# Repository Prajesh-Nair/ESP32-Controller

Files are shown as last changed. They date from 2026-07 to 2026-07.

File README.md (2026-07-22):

# J-Deck

<p align="center">
  <strong>An ESP32-C3 wireless controller for JATAYU and any Wi-Fi, Bluetooth, or ESP-NOW project.</strong><br />
  Compact in your hands. Fast on the link. Built to control.
</p>

<p align="center">
  
  
  
  
</p>

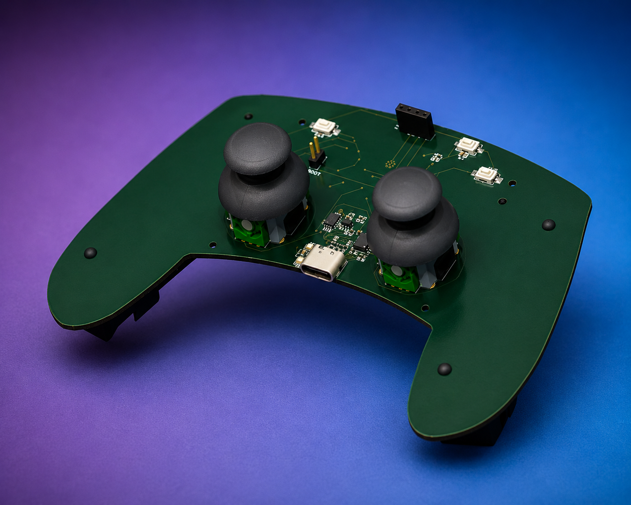
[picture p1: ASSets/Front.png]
J-Deck hero image - assembled remote


## Built for JATAYU. Ready for anything.

J-Deck is a purpose-built handheld wireless controller. Its primary role is to talk directly to the **JATAYU Flight Controller**, reading pilot inputs from twin analog joysticks and tactile controls before sending compact control data over **ESP-NOW**.

But it is not limited to flight. With its ESP32-C3 radio and programmable firmware, J-Deck can be adapted as a controller for robots, RC vehicles, smart-home projects, camera rigs, simulators, or any device that communicates through **Wi-Fi**, **Bluetooth Low Energy (BLE)**, or **ESP-NOW**.

No router is required for ESP-NOW. For other projects, choose the wireless mode and control protocol that best fits the device you are building.

> This repository contains the KiCad hardware design for the controller. Firmware, final protocol definitions, pin mappings, and flight-safety behaviour should be kept versioned alongside the matching JATAYU Flight Controller project.

## Wireless modes

| Mode | Great for | Typical connection |
| --- | --- | --- |
| ESP-NOW | Responsive device-to-device control, including JATAYU | Direct peer-to-peer packets; no access point required |
| Wi-Fi | Web dashboards, LAN-connected devices, and IoT projects | Connect through an access point or run a local access point |
| Bluetooth LE | Phones, tablets, and low-power nearby peripherals | BLE pairing and GATT services |

The controller hardware stays the same; the firmware defines the selected radio mode, packet format, mapping, and receiver behaviour.

## The link

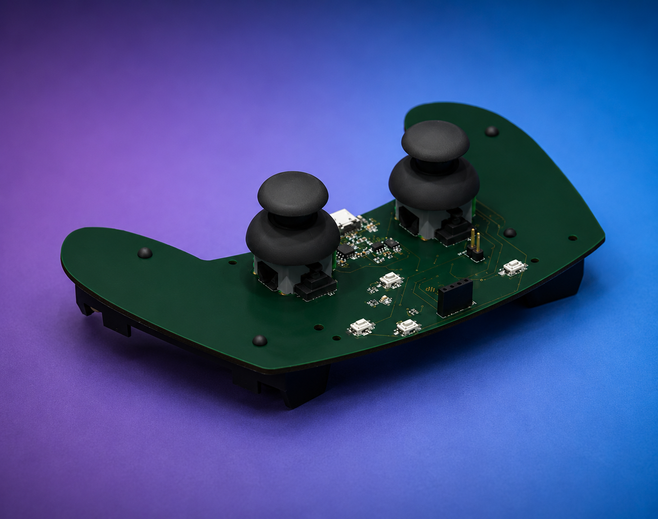
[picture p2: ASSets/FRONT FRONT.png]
ESP-NOW telemetry flow placeholder - replace with a protocol or range-test graphic


```text
[J-Deck] -- ESP-NOW control packets --> [JATAYU Flight Controller]
[J-Deck] <-- optional telemetry ----- [JATAYU Flight Controller]
```

ESP-NOW is a strong fit for a dedicated RC link because it operates without a conventional Wi-Fi access point and keeps the radio exchange focused on the aircraft. The exact packet format, peer MAC addresses, update rate, channel, checksum, and failsafe timeout are firmware decisions - document them here when the flight stack is locked.

## Hardware

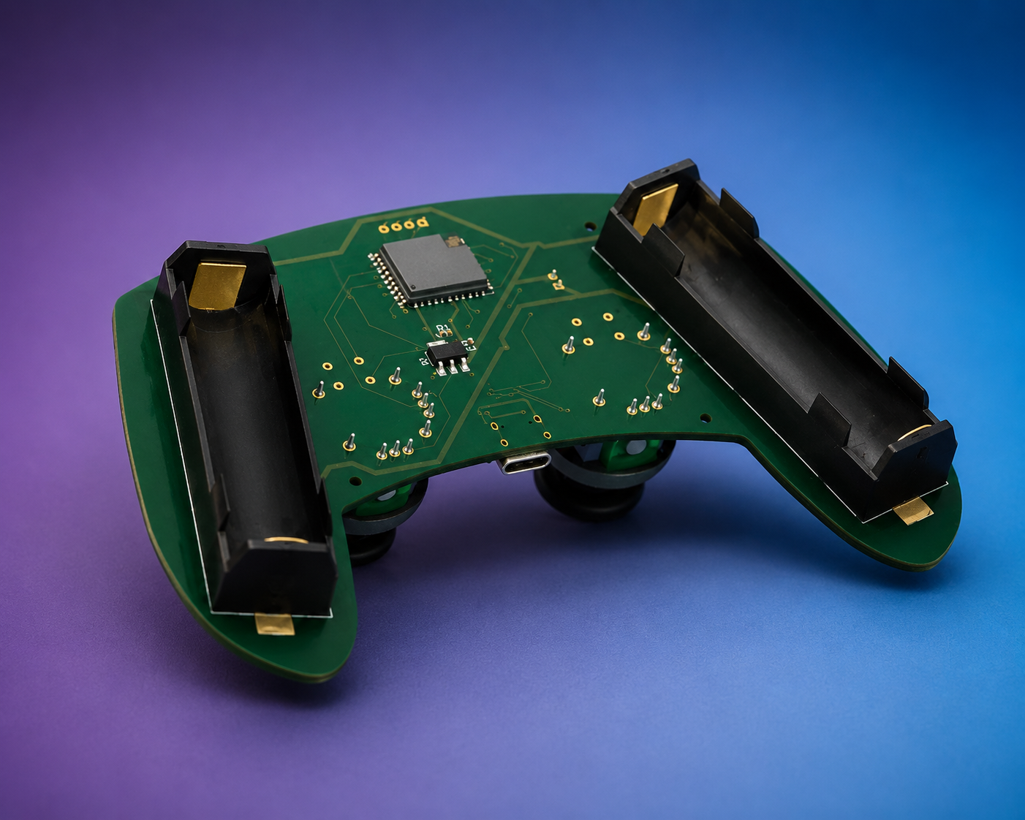
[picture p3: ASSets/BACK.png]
PCB render placeholder - replace with front/back board render or assembled-controller photo


| Feature | Design choice |
| --- | --- |
| Brain | ESP32-C3-WROOM-02U - RISC-V MCU with 2.4 GHz radio |
| Flight controls | Two 2-axis analog joysticks |
| Extra input | Four tactile push buttons |
| Charging | USB-C input with TP4056 single-cell LiPo charger |
| Battery protection | DW01A + FS8205A protection stage |
| Regulation | AP2114H 3.3 V LDO |
| Feedback | Charge/status LEDs |

## Power

The controller is designed around a **single-cell 3.7 V LiPo battery**. USB-C feeds the onboard charger, while the battery protection circuit guards against over-charge, over-discharge, and over-current conditions. The 3.3 V regulator supplies the ESP32-C3 and controls.

**Treat lithium batteries with care:** use a protected, suitable 1S cell; inspect wiring and polarity before power-up; and never leave charging unattended.

## Repository map

```text
JATAYU-Controller.kicad_pro   KiCad project
JATAYU-Controller.kicad_sch   Schematic
JATAYU-Controller.kicad_pcb   PCB layout
JATAYU-Controller-BOM.csv     Bill of materials
GERBER/                       Manufacturing outputs
3D Files/                     Mechanical / enclosure assets
```

## Getting started

1. Open `JATAYU-Controller.kicad_pro` in KiCad.
2. Review the schematic, footprints, board rules, and antenna keep-out before ordering.
3. Generate fresh manufacturing files from the validated board revision.
4. Assemble and bring up the power rails first, then program and test the ESP-NOW firmware with the JATAYU Flight Controller.
5. Validate radio range, packet loss, neutral-stick calibration, arming logic, and failsafe behaviour **with props removed** before any flight test.

## Flight safety

This is an experimental flight-control device. A radio link must never be the only safety layer. The aircraft firmware should implement a conservative failsafe when packets stop arriving, reject malformed packets, require deliberate arming, and be tested in a controlled environment. Always follow applicable local regulations.

## Image checklist

The three placeholder images above are ready to be replaced with your own project shots:

1. A clean, assembled-controller hero photo.
2. An ESP-NOW architecture, telemetry, or range-test graphic.
3. A KiCad 3D render or close-up PCB photo.

---

<p align="center">Made for the <strong>JATAYU</strong> flight platform.</p>

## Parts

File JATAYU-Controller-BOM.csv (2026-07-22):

Reference | Qty | Value | DNP | Exclude from BOM | Exclude from Board | Footprint | Datasheet
Battery1 | 1 | Conn_01x02_Pin |  |  |  | Connector_PinHeader_2.54mm:PinHeader_1x02_P2.54mm_Vertical | ~
C1,C2,C4,C5 | 4 | 10uF |  |  |  | Capacitor_SMD:C_0603_1608Metric | https://robu.in/product/0603x106m160nt-fh-16v-10uf-x5r%c2%b120-0603-multilayer-ceramic-capacitors-mlcc-smd-smt-rohs/,~
C3 | 1 | 0.1uF |  |  |  | Capacitor_SMD:C_0603_1608Metric | ~
C7 | 1 | 1uF |  |  |  | Capacitor_SMD:C_0603_1608Metric | https://robu.in/product/0603b105k160nt-fh-16v-1uf-x7r%c2%b110-0603-multilayer-ceramic-capacitors-mlcc-smd-smt-rohs/
D1,D2 | 2 | CHRG-LED |  |  |  | LED_SMD:LED_0805_2012Metric | ~
D5 | 1 | LED |  |  |  | LED_SMD:LED_0805_2012Metric | ~
J1 | 1 | USB_C_Receptacle_USB2.0_14P |  |  |  | Connector_USB:USB_C_Receptacle_GCT_USB4105-xx-A_16P_TopMnt_Horizontal | https://robu.in/product/type-c-31-m-12-hroparts-5a-1-16p-female-type-c-smd-usb-connectors-rohs/?gad_source=1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
J2 | 1 | Conn_01x04_Socket |  |  |  | Connector_PinSocket_2.54mm:PinSocket_1x04_P2.54mm_Vertical | ~
Q1 | 1 | FS8205A |  |  |  | FS8205A:SOP65P640X120-8N
R1,R2 | 2 | 22 |  |  |  | Resistor_SMD:R_0603_1608Metric | https://robu.in/product/ac0603fr-0722rl-yageo-res-thick-film-0603-22-ohm-1-0-1w1-10w-%c2%b1100ppm-c-pad-smd-t-r-automotive-aec-q200/
R3,R8 | 2 | 5.1K |  |  |  | Resistor_SMD:R_0603_1608Metric | https://robu.in/product/rt0603fre075k1l-yageo-100mw-thin-film-resistor-75v-%c2%b150ppm-%e2%84%83-%c2%b11-5-1k%cf%89-0603-chip-resistor-surface-mount-rohs/
R4 | 1 | 1.2K |  |  |  | Resistor_SMD:R_0603_1608Metric | ~
R5 | 1 | 0.4 |  |  |  | Resistor_SMD:R_0603_1608Metric | ~
R6,R7,R9 | 3 | 1K |  |  |  | Resistor_SMD:R_0603_1608Metric | ~
R10 | 1 | 100 |  |  |  | Resistor_SMD:R_0603_1608Metric | ~
R14,R15 | 2 | 10K |  |  |  | Resistor_SMD:R_0603_1608Metric | https://robu.in/product/ac0603fr-0710kl-yageo-res-thick-film-0603-10k-ohm-1-0-1w1-10w-%c2%b1100ppm-c-pad-smd-t-r-automotive-aec-q200/
R16 | 1 | 220 |  |  |  | Resistor_SMD:R_0603_1608Metric | ~
SW1,SW2,SW3,SW4 | 4 | SW_Push |  |  |  | Button_Switch_SMD:SW_Tactile_SPST_NO_Straight_CK_PTS636Sx25SMTRLFS | https://robu.in/product/tsb008a2526a-bzcn-3-5mm-2-5mm-rectangle-button-50ma-standing-paste-6mm-260gf-12v-smd-tactile-switches-rohs/,~
U1 | 1 | Stick 1 |  |  |  | COM-09032:XDCR_COM-09032
U2 | 1 | Stick 2 |  |  |  | COM-09032:XDCR_COM-09032
U3 | 1 | TP4056 |  |  |  | Package_SO:SOIC-8-1EP_3.9x4.9mm_P1.27mm_EP2.41x3.3mm_ThermalVias | https://www.lcsc.com/datasheet/lcsc_datasheet_2410121619_TOPPOWER-Nanjing-Extension-Microelectronics-TP4056-42-ESOP8_C16581.pdf
U4 | 1 | DW01A |  |  |  | Package_TO_SOT_SMD:SOT-23-6 | https://hmsemi.com/downfile/DW01A.PDF
U5 | 1 | AP2114H-3.3TRG1 |  |  |  | Package_TO_SOT_SMD:SOT-223-3_TabPin2 | https://www.lioncircuits.com/parts/AP2114H-3.3TRG1
U6 | 1 | ESP32-C3-WROOM-02U |  |  |  | RF_Module:ESP32-C3-WROOM-02U | https://www.espressif.com/sites/default/files/documentation/esp32-c3-wroom-02_datasheet_en.pdf

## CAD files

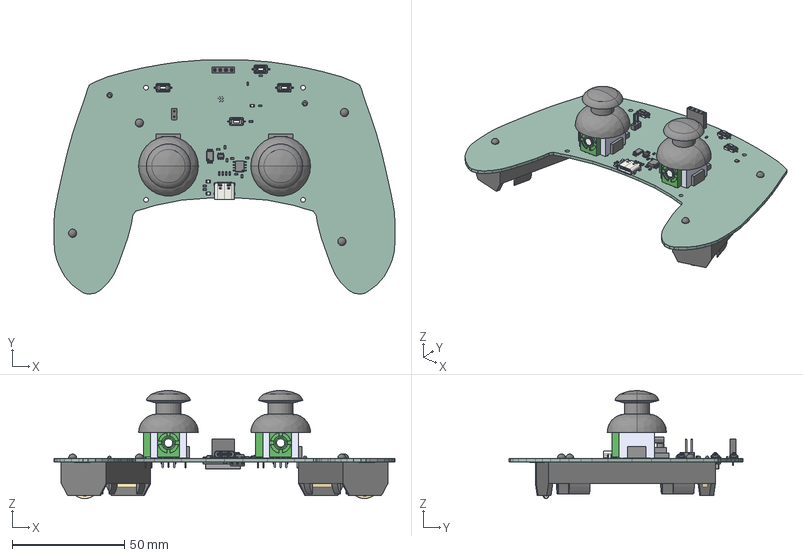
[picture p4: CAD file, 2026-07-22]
3D Files/JATAYU-Controller-PCB.step
152.0 x 104.5 x 48.2 mm
SW_Tactile_SPST_NO_Straight_CK_PTS636Sx25SMTRLFS x 4
COM-09032 x 2
C_0603_1608Metric x 6
R_0603_1608Metric x 13
SOT-23-6
LED_0805_2012Metric x 3
FS8205A
TP4056--3DModel-STEP-56544
PinHeader_1x02_P2.54mm_Vertical
PinSocket_1x04_P2.54mm_Vertical
USB_C_Receptacle_GCT_USB4105-xx-A_16P_TopMnt_Horizontal
SOT-223
BatteryHolder_Keystone_1042_1x18650 x 2
ESP32-C3-WROOM-02U
JATAYU-Controller_PCB

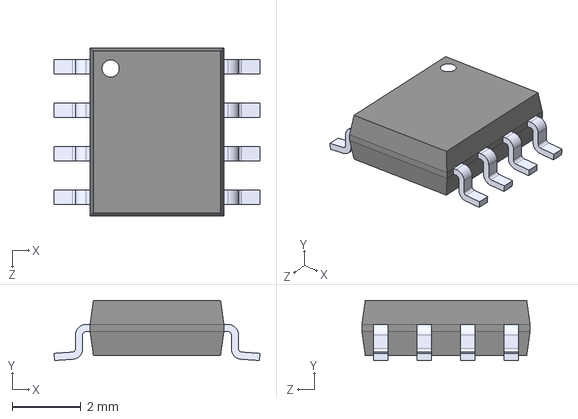
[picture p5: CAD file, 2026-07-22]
EXTRA ASSETS FOR KICAD/COM-09032/TP4056--3DModel-STEP-56544.STEP
6.00 x 1.75 x 4.90 mm

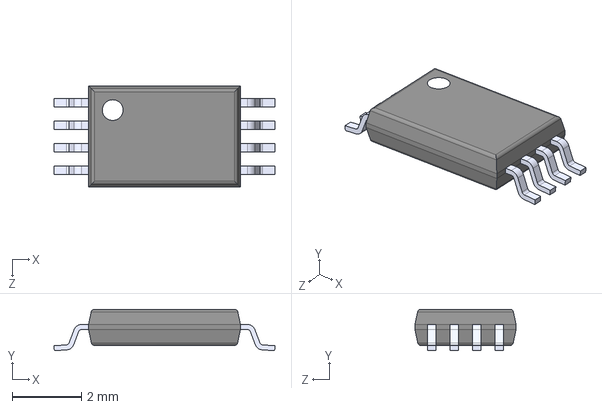
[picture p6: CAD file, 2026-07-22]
EXTRA ASSETS FOR KICAD/FS8205A/FS8205A.step
6.40 x 1.20 x 2.93 mm

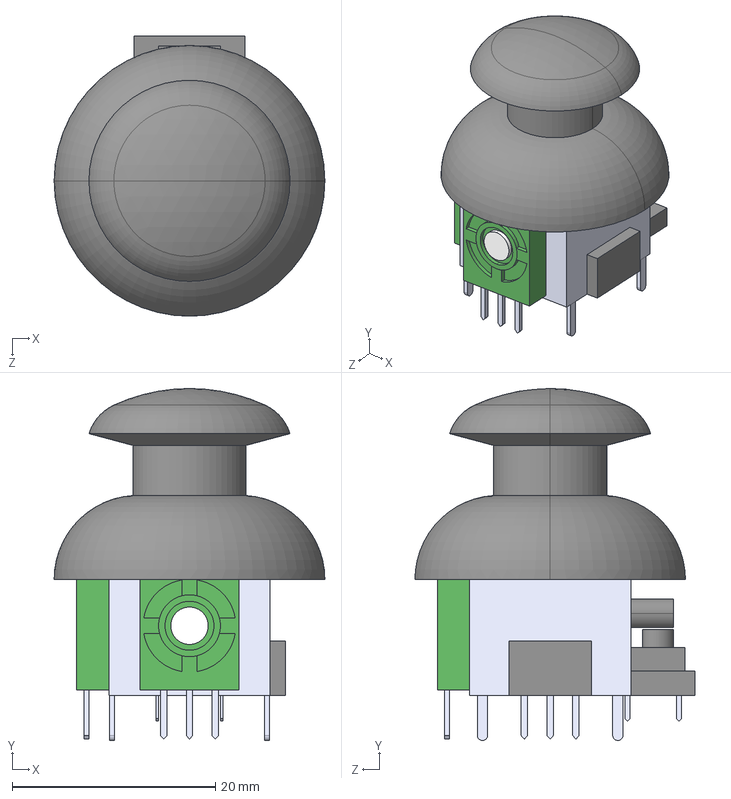
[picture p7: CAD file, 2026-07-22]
EXTRA ASSETS FOR KICAD/COM-09032/COM-09032.step
26.7 x 34.7 x 27.6 mm

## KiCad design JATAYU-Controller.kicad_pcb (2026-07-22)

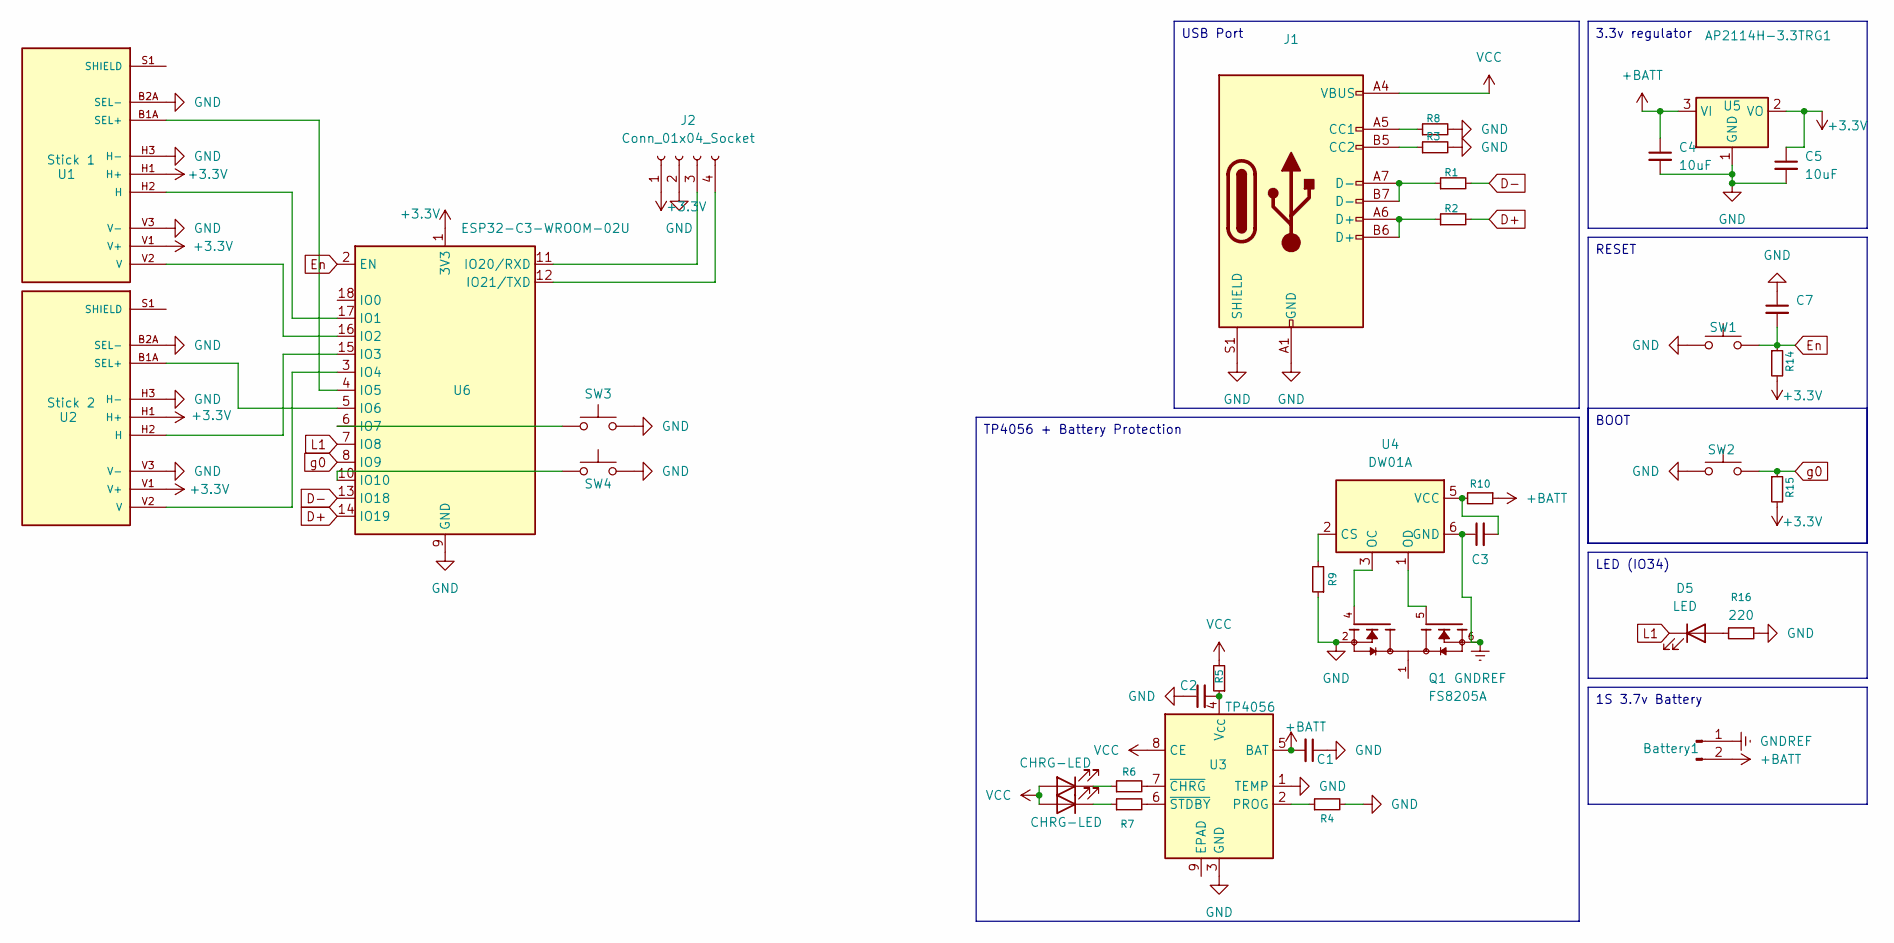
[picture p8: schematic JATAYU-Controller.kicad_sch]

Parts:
Battery1: Conn_01x02_Pin; PinHeader_1x02_P2.54mm_Vertical
C1, C2, C4, C5: 10uF; C_0603_1608Metric
C3: 0.1uF; C_0603_1608Metric
C7: 1uF; C_0603_1608Metric
D1, D2: CHRG-LED; LED_0805_2012Metric
D5: LED; LED_0805_2012Metric
J1: USB_C_Receptacle_USB2.0_14P; USB_C_Receptacle_GCT_USB4105-xx-A_16P_TopMnt_Horizontal
J2: Conn_01x04_Socket; PinSocket_1x04_P2.54mm_Vertical
Q1: FS8205A; SOP65P640X120-8N; PARTREV 1.7
R1, R2: 22; R_0603_1608Metric
R3, R8: 5.1K; R_0603_1608Metric
R4: 1.2K; R_0603_1608Metric
R5: 0.4; R_0603_1608Metric
R6, R7, R9: 1K; R_0603_1608Metric
R10: 100; R_0603_1608Metric
R14, R15: 10K; R_0603_1608Metric
R16: 220; R_0603_1608Metric
SW1, SW2, SW3, SW4: SW_Push; SW_Tactile_SPST_NO_Straight_CK_PTS636Sx25SMTRLFS
U1: Stick 1; XDCR_COM-09032; PARTREV N/A
U2: Stick 2; XDCR_COM-09032; PARTREV N/A
U3: TP4056; SOIC-8-1EP_3.9x4.9mm_P1.27mm_EP2.41x3.3mm_ThermalVias
U4: DW01A; SOT-23-6
U5: AP2114H-3.3TRG1; SOT-223-3_TabPin2
U6: ESP32-C3-WROOM-02U

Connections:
+3.3V: C5.1, J2.1, R14.2, R15.2, U1.H1 (H+), U1.V1 (V+), U2.H1 (H+), U2.V1 (V+), U5.2 (VO), U6.1 (3V3)
+BATT: Battery1.2, C1.2, C4.1, R10.1, U3.5 (BAT), U5.3 (VI); also elsewhere on the board
D+: R2.2, U6.14 (IO19)
D-: R1.2, U6.13 (IO18)
En: C7.2, R14.1, SW1.2, U6.2 (EN)
GND: C1.1, C2.1, C4.2, C5.2, C7.1, J1.A1 (GND), J1.A12 (GND), J1.B1 (GND), J1.B12 (GND), J1.S1 (SHIELD), J2.2, Q1.2, Q1.3, R3.2, R4.2, R8.2, R9.1, R16.1, SW1.1, SW2.1, SW3.2, SW4.2, U1.B2A (SEL-), U1.H3 (H-), U1.V3 (V-), U2.B2A (SEL-), U2.H3 (H-), U2.V3 (V-), U3.1 (TEMP), U3.3 (GND), U5.1 (GND), U6.9 (GND), U6.19 (GND)
GNDREF: Battery1.1, C3.1, Q1.6, Q1.7, U4.6 (GND); also elsewhere on the board
L1: D5.1 (K), U6.7 (IO8)
unnamed: D1.1 (K), R6.1
unnamed: D2.1 (K), R7.1
unnamed: D5.2 (A), R16.2
unnamed: J1.A5 (CC1), R8.1
unnamed: J1.B5 (CC2), R3.1
unnamed: J1.A6 (D+), J1.B6 (D+), R2.1
unnamed: J1.A7 (D-), J1.B7 (D-), R1.1
unnamed: J2.3, U6.11 (IO20/RXD)
unnamed: J2.4, U6.12 (IO21/TXD)
unnamed: Q1.1, Q1.8
unnamed: U1.H2 (H), U6.17 (IO1)
unnamed: U1.B1A (SEL+), U6.4 (IO5)
unnamed: U1.S1 (SHIELD), U1.S2 (SHIELD), U1.S3 (SHIELD), U1.S4 (SHIELD)
unnamed: U1.V2 (V), U6.16 (IO2)
unnamed: U2.H2 (H), U6.15 (IO3)
unnamed: U2.B1A (SEL+), U6.5 (IO6)
unnamed: U2.S1 (SHIELD), U2.S2 (SHIELD), U2.S3 (SHIELD), U2.S4 (SHIELD)
unnamed: U2.V2 (V), U6.3 (IO4)
unnamed: R4.1, U3.2 (PROG)
unnamed: C2.2, R5.1, U3.4 (V_{CC})
unnamed: R6.2, U3.7 (~CHRG)
unnamed: R7.2, U3.6 (~STDBY)
unnamed: R9.2, U4.2 (CS)
unnamed: Q1.4, U4.3 (OC)
unnamed: Q1.5, U4.1 (OD)
unnamed: C3.2, R10.2, U4.5 (VCC)
unnamed: SW3.1, U6.6 (IO7)
unnamed: SW4.1, U6.10 (IO10)
VCC: D1.2 (A), D2.2 (A), J1.A4 (VBUS), J1.A9 (VBUS), J1.B4 (VBUS), J1.B9 (VBUS), R5.2, U3.8 (CE)
g0: R15.1, SW2.2, U6.8 (IO9)

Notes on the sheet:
USB Port
TP4056 + Battery Protection
1S 3.7v Battery
RESET
BOOT
LED (IO34)
3.3v regulator

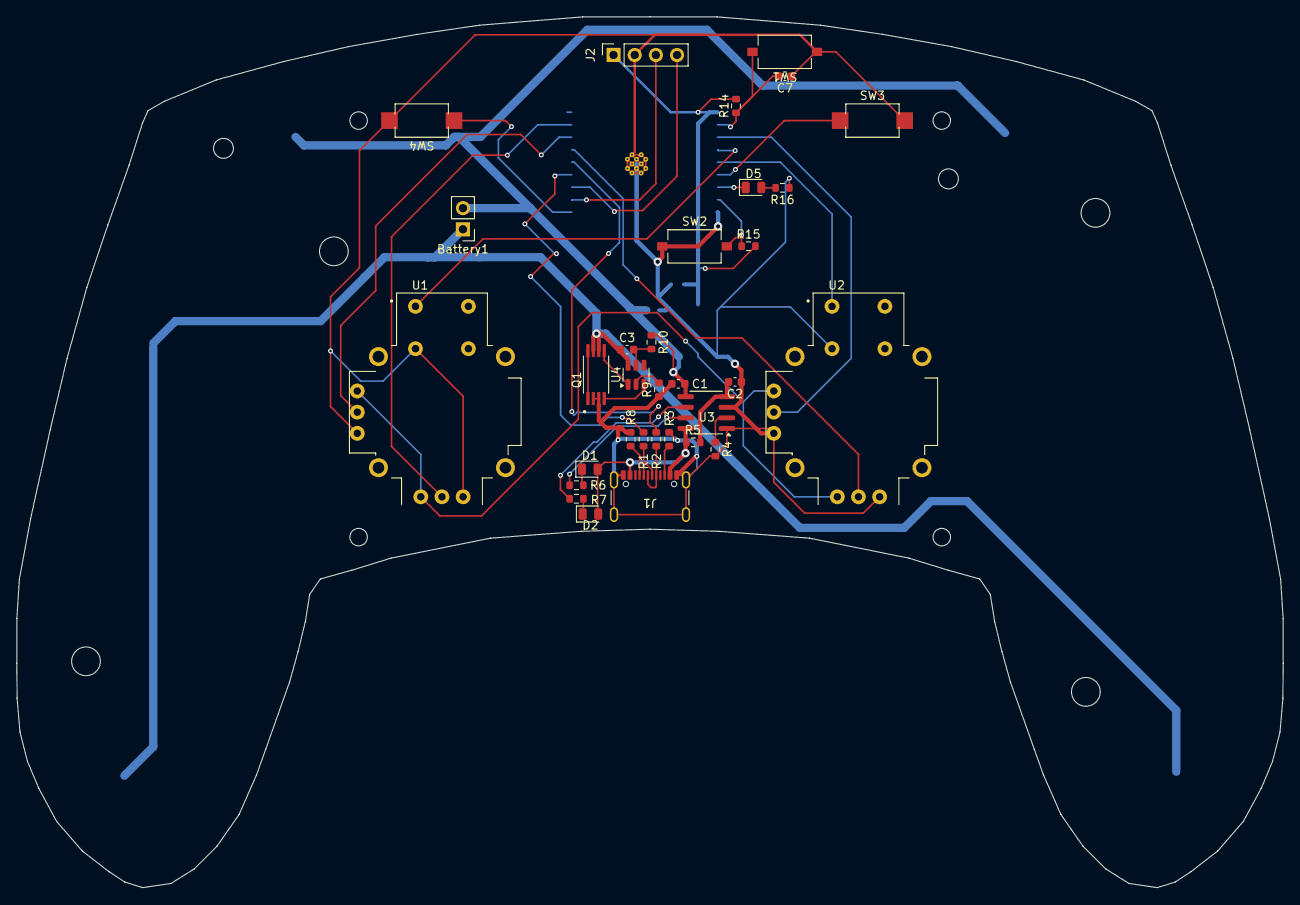
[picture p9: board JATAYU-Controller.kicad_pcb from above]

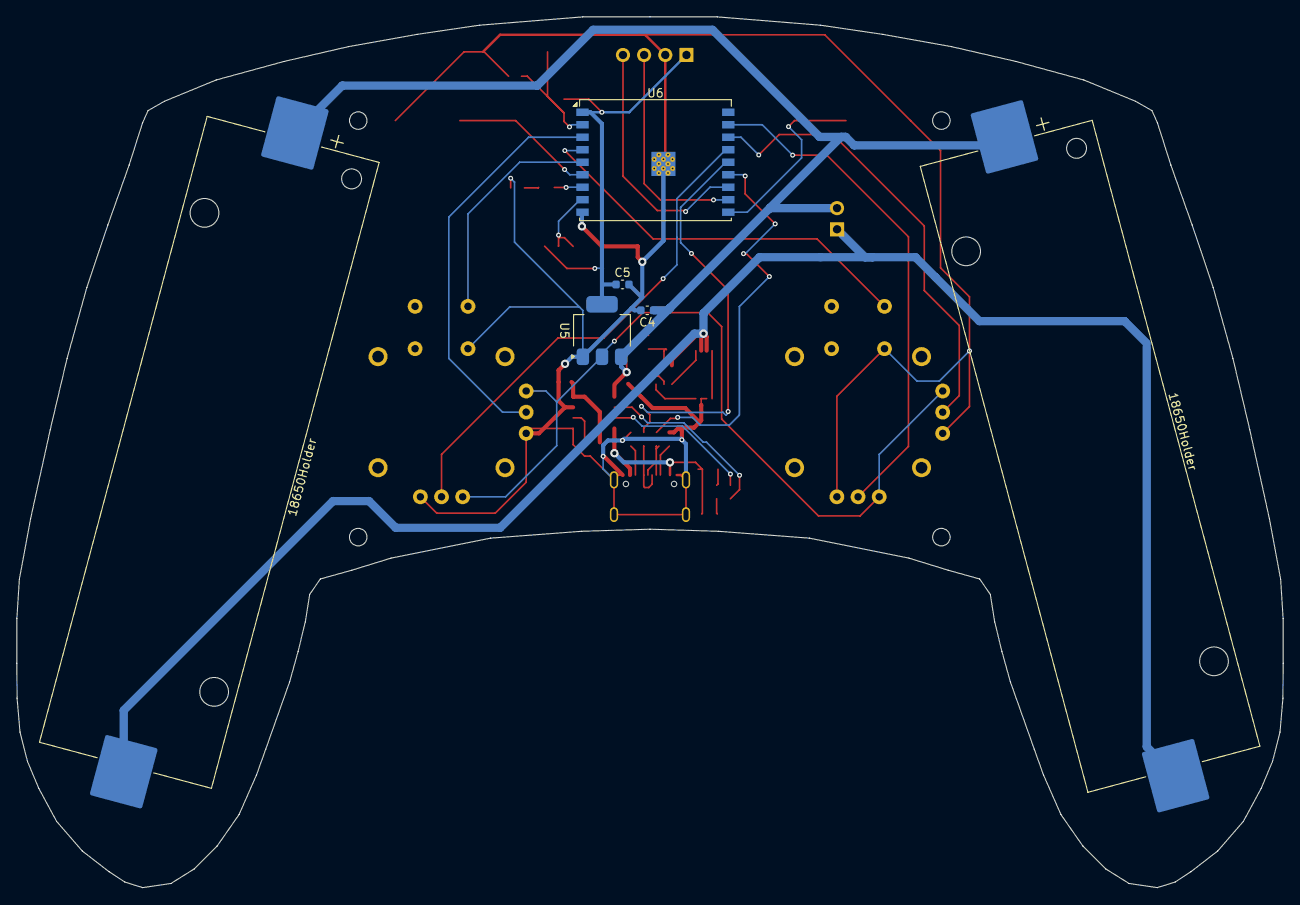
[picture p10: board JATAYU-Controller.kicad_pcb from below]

Board: 2 copper layers, 152.0 x 104.5 mm, 38 parts (6 on the bottom side), 38 nets.

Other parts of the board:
18650Holder, 18650Holder#2: 18650; BatteryHolder_Keystone_1042_1x18650

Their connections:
+BATT: 18650Holder.1, 18650Holder#2.1; also elsewhere on the board
GNDREF: 18650Holder.2, 18650Holder#2.2; also elsewhere on the board
